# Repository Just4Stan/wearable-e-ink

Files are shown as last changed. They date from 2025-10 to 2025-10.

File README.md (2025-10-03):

# Wearable-E-Ink
A beginner-friendly soldering workshop project to build a WiFi-enabled, programmable e-paper name badge. This project is designed to be completed in a 2-3 hour session, teaching participants how to solder both through-hole and surface-mount (SMD) components.

Initial designed to give workshops at HighTechLab in Leuven



# Block Diagram


(AI generated for simple overview)
See the kicad files for schematics and PCB design

# Display

See datasheet for "GDEM0154Z91" 

# CAD

OnShape: https://cad.onshape.com/documents/da012de4a02ab2054a0e627e/w/e4c4a902931b74520d1464dc/e/3234466a68d54d344f0d976d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





# Features
- ESP8266 Powered: Uses the powerful ESP-12F module for WiFi connectivity and control.
- High-Contrast Display: Features a 1.54-inch, 200x200 pixel black and white e-paper screen.
- Beginner-Friendly Design: The PCB is laid out with "progressive difficulty," starting with easy components to build confidence before moving to more challenging SMD parts.
- USB-C Connectivity: Modern, robust connector for power and programming.
- Web Updatable: Firmware supports updating the display content via a simple web API over WiFi.
- Fully Open Source: The hardware design and firmware are free to use, modify, and distribute.

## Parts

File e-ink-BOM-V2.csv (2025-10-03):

Reference | Value | Footprint | Datasheet | Qty | DNP | Exclude from BOM | Exclude from Board
C4,C7 | 10uF | wearable-e-inks:C1206 | https://item.szlcsc.com/89171.html | 2
C5,C6,C8 | 100nF | wearable-e-inks:C1206 | https://item.szlcsc.com/89171.html | 3
C9,C10,C11,C12,C13,C14,C18 | 1uF | wearable-e-inks:C1206 | https://item.szlcsc.com/89171.html | 7
C16,C17 | 4.7uF | wearable-e-inks:C1206 | https://item.szlcsc.com/89171.html | 2
D1,D2,D3 | shottky | wearable-e-inks:SOD-123_L2.8-W1.8-LS3.7-RD | https://item.szlcsc.com/301422.html | 3
L2 | 47uF | wearable-e-inks:IND-SMD_L4.0-W4.0 | https://item.szlcsc.com/109498.html | 1
LED1 | RED LED | wearable-e-inks:LED1206-R-RD_RED | https://item.szlcsc.com/73803.html | 1
R3 | 1MR | wearable-e-inks:R1206 | https://item.szlcsc.com/311874.html | 1
R4,R5,R6,R7,R8,R9,R13 | 5.1k | wearable-e-inks:R1206 | https://item.szlcsc.com/311874.html | 7
R10,R11,R12 | 220Ohm | wearable-e-inks:R1206 | https://item.szlcsc.com/311874.html | 3
R14 | 2.2R | wearable-e-inks:R1206 | https://item.szlcsc.com/311874.html | 1
U1,U8 | 4*4*1_7 | wearable-e-inks:SW-SMD_4P-L5.2-W5.2-P3.70-LS6.5 | https://lcsc.com/product-detail/Tactile-Switches_BOOMELE-Boom-Precision-Elec-4-4-1-7_C10852.html | 2
U3 | CH340C_USB | wearable-e-inks:SOP-16_L10.0-W3.9-P1.27-LS6.0-BL | https://item.szlcsc.com/391677.html | 1
U4 | N-MOS | wearable-e-inks:SOT-23-LDO | https://item.szlcsc.com/236142.html | 1
U5 | ESP-12F(ESP8266MOD) | wearable-e-inks:WIFIM-SMD_ESP-12F-ESP8266MOD | https://item.szlcsc.com/84052.html | 1
U6 | TYPE-C | wearable-e-inks:USB-C_SMD-TYPE-C-31-M-12_1 | https://item.szlcsc.com/datasheet/TYPE-C-31-M-12/177331.html | 1
U7 | LDO | wearable-e-inks:SOT-23-LDO | https://item.szlcsc.com/14454.html | 1
U9,U10 | NPN | wearable-e-inks:SOT-23-LDO | https://www.diodes.com/assets/Package-Files/SOT23.pdf | 2
U11 | 05A20H24P | wearable-e-inks:FPC-SMD_24P-P0.50_05A20H24P | https://atta.szlcsc.com/upload/public/pdf/source/20230308/DA2EF4811240A4022FFA3B04CDFA2A9C.pdf | 1

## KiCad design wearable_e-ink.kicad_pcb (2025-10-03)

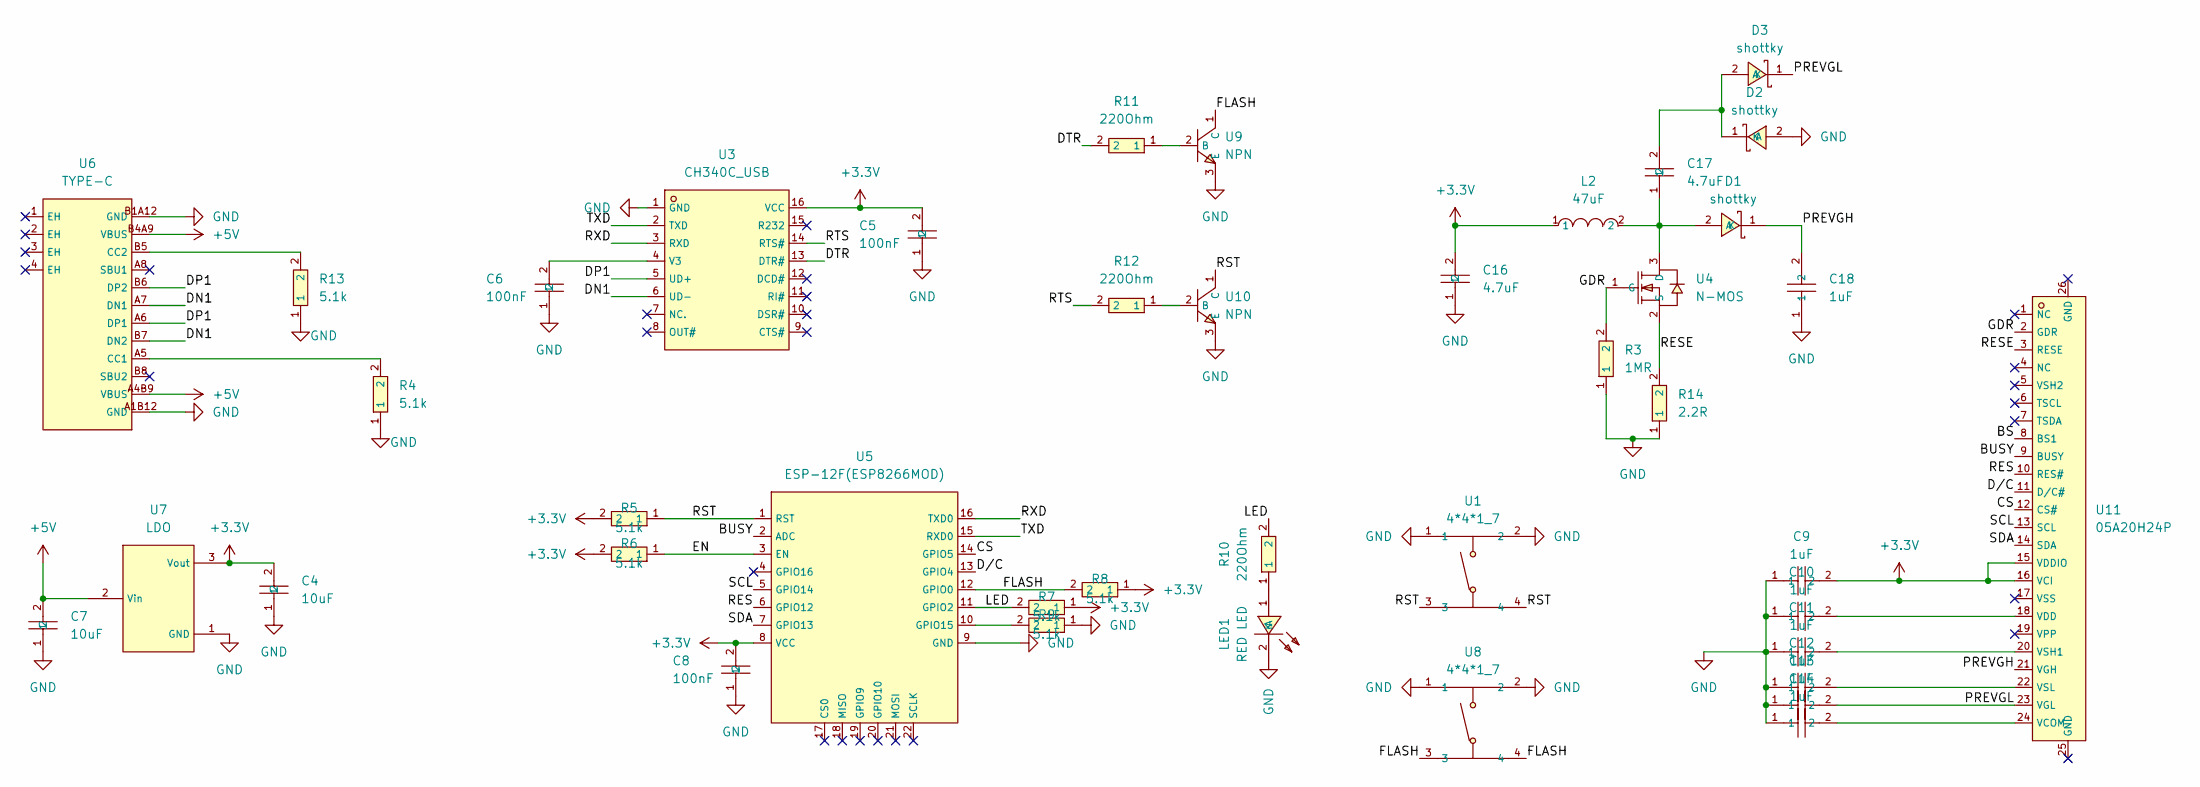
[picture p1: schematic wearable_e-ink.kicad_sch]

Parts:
C4, C7: 10uF; C1206; LCSC C1849
C5, C6, C8: 100nF; C1206; LCSC C1945
C9, C10, C11, C12, C13, C14, C18: 1uF; C1206; LCSC C1848
C16, C17: 4.7uF; C1206; LCSC C1872
D1, D2, D3: shottky; SOD-123_L2.8-W1.8-LS3.7-RD; LCSC C18863
L2: 47uF; IND-SMD_L4.0-W4.0; LCSC C76869
LED1: RED LED; LED1206-R-RD_RED; LCSC C49018
R3: 1MR; R1206; LCSC C17927
R4, R5, R6, R7, R8, R9, R13: 5.1k; R1206; LCSC C26033
R10, R11, R12: 220Ohm; R1206; LCSC C17957
R14: 2.2R; R1206; LCSC C17947
U1, U8: 4*4*1_7; SW-SMD_4P-L5.2-W5.2-P3.70-LS6.5; LCSC C10852
U3: CH340C_USB; SOP-16_L10.0-W3.9-P1.27-LS6.0-BL; LCSC C7464026
U4: N-MOS; SOT-23-LDO; LCSC C2588
U5: ESP-12F(ESP8266MOD); WIFIM-SMD_ESP-12F-ESP8266MOD; LCSC C82891
U6: TYPE-C; USB-C_SMD-TYPE-C-31-M-12_1; LCSC C165948
U7: LDO; SOT-23-LDO; LCSC C5446
U9, U10: NPN; SOT-23-LDO; LCSC C8533
U11: 05A20H24P; FPC-SMD_24P-P0.50_05A20H24P; LCSC C5362175

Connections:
+3.3V: C4.2, C5.2, C8.2, C9.2, C16.2, L2.1, R5.2, R6.2, R7.1, R8.1, U3.16 (VCC), U5.8 (VCC), U7.3 (Vout), U11.15 (VDDIO), U11.16 (VCI)
+5V: C7.2, U6.A4B9 (VBUS), U6.B4A9 (VBUS), U7.2 (Vin)
/BS: U11.8 (BS1)
/BUSY: U5.2 (ADC), U11.9 (BUSY)
/CS: U5.14 (GPIO5), U11.12 (CS#)
/DN1: U3.6 (UD-), U6.A7 (DN1), U6.B7 (DN2)
/DP1: U3.5 (UD+), U6.A6 (DP1), U6.B6 (DP2)
/DTR: R11.2, U3.13 (DTR#)
/D/C: U5.13 (GPIO4), U11.11 (D/C#)
/EN: R6.1, U5.3 (EN)
/FLASH: R8.2, U5.12 (GPIO0), U8.3, U8.4, U9.1 (C)
/GDR: R3.2, U4.1 (G), U11.2 (GDR)
/LED: R7.2, R10.2, U5.11 (GPIO2)
/PREVGH: C18.2, D1.1 (K), U11.21 (VGH)
/PREVGL: C13.2, D3.1 (K), U11.23 (VGL)
/RES: U5.6 (GPIO12), U11.10 (RES#)
/RESE: R14.2, U4.2 (S), U11.3 (RESE)
/RST: R5.1, U1.3, U1.4, U5.1 (RST), U10.1 (C)
/RTS: R12.2, U3.14 (RTS#)
/RXD: U3.3 (RXD), U5.16 (TXD0)
/SCL: U5.5 (GPIO14), U11.13 (SCL)
/SDA: U5.7 (GPIO13), U11.14 (SDA)
/TXD: U3.2 (TXD), U5.15 (RXD0)
GND: C4.1, C5.1, C6.1, C7.1, C8.1, C9.1, C10.1, C11.1, C12.1, C13.1, C14.1, C16.1, C18.1, D2.2 (A), LED1.2 (K), R3.1, R4.1, R9.1, R13.1, R14.1, U1.1, U1.2, U3.1 (GND), U5.9 (GND), U6.A1B12 (GND), U6.B1A12 (GND), U7.1 (GND), U8.1, U8.2, U9.3 (E), U10.3 (E)
unnamed: C17.1, D1.2 (A), L2.2, U4.3 (D)
unnamed: C17.2, D2.1 (K), D3.2 (A)
unnamed: LED1.1 (A), R10.1
unnamed: C6.2, U3.4 (V3)
unnamed: R9.2, U5.10 (GPIO15)
unnamed: R4.2, U6.A5 (CC1)
unnamed: R13.2, U6.B5 (CC2)
unnamed: R11.1, U9.2 (B)
unnamed: R12.1, U10.2 (B)
unnamed: C14.2, U11.24 (VCOM)
unnamed: C10.2, U11.18 (VDD)
unnamed: C11.2, U11.20 (VSH1)
unnamed: C12.2, U11.22 (VSL)

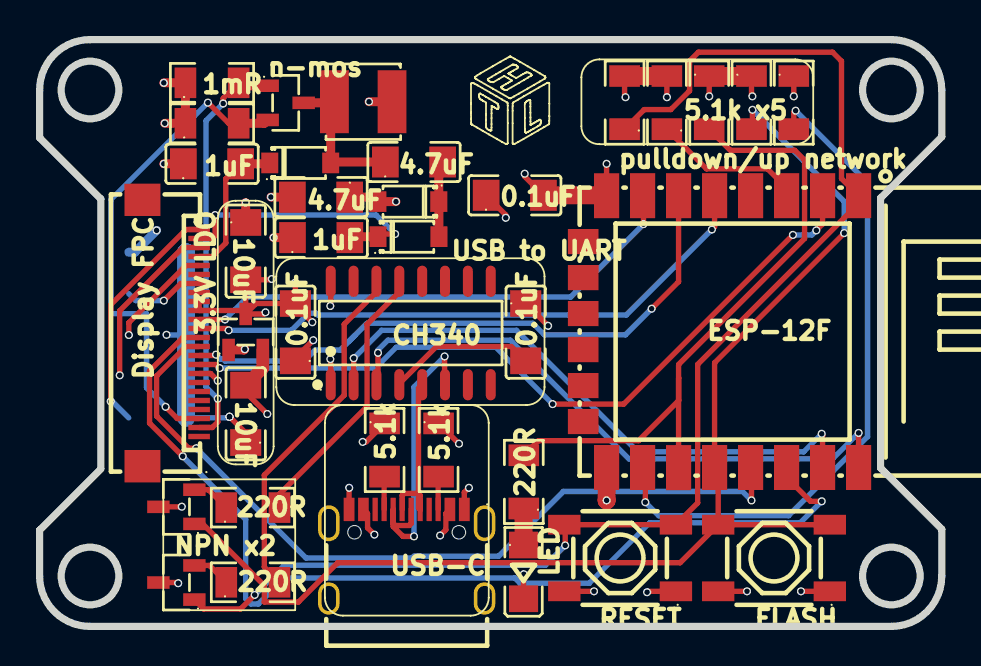
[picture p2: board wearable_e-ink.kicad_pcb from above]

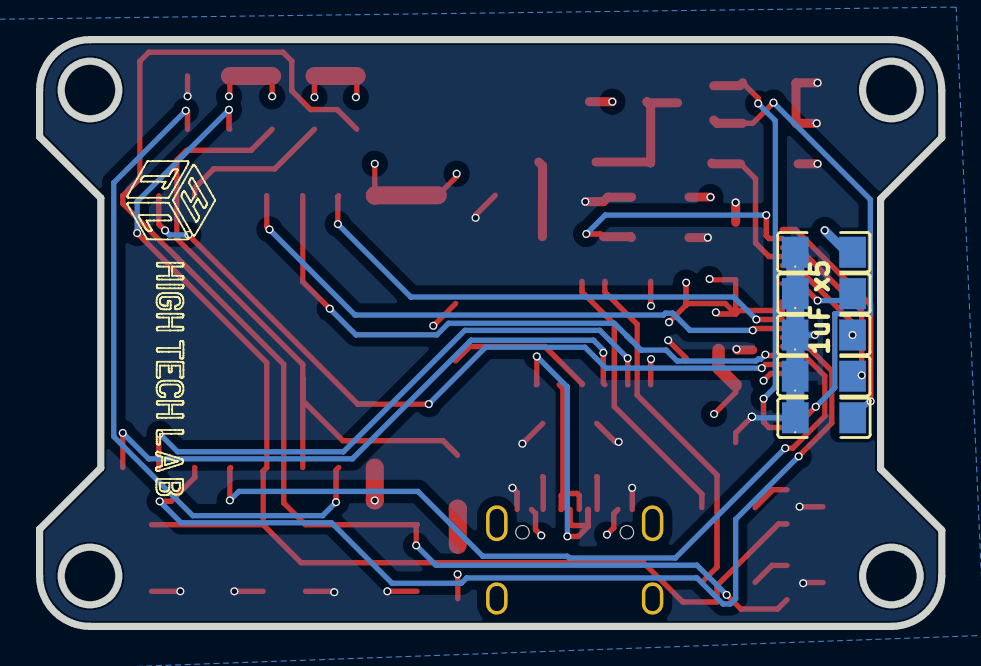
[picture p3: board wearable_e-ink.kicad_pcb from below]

Board: 4 copper layers, 50.1 x 32.6 mm, 41 parts (5 on the bottom side), 36 nets.

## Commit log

2025-10-02 First schematic rev and component selection
    [wearable_e-ink.kicad_pcb, wearable_e-ink.kicad_sch]
2025-10-02 added BOM
    [e-ink-BOM.csv]
2025-10-02 First pcb design layout
    [wearable_e-ink.kicad_pcb, wearable_e-ink.kicad_sch]
2025-10-03 Switched out daughter board for on-board FPC and display signal conditioning. First of V2
    [bom.csv, designators.csv, e-ink-BOM-V2.csv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]
2025-10-03 added CAD
2025-10-03 Final V2 Exports
    [bom.csv, designators.csv, positions.csv]
